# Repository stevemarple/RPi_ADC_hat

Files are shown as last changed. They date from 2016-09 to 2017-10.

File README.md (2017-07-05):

# Raspberry Pi ADC hat

A Raspberry Pi hat using the Microchip MCP3424 analogue to digital
converter. The hat also has connectors for I2C and 1-wire interfaces,
and two switched outputs, for instance to control fans, motors or
relays. A Honeywell HIH6130-021 or HIH6131-021 I2C temperature and
humidity sensor can also be fitted.

## Hardware features

### Analogue to digital converter

The MCP3424 is a 4 channel 18 bit differential input analogue to
digital converter. Sample rates are 3.75 SPS (samples per second) at
18 bit resolution, 15 SPS at 16 bit resolution, 60 SPS at 14 bit
resolution and 240 SPS at 12 bit resolution. When single-ended inputs
are used the resolution is reduced by 1 bit. A jumper block enables
the I2C address of the MCP3424 to be selected from eight possible
values. The ADC inputs are directly wired to a 9 pin D connector, 3
channels can be used for differential inputs, the fourth for
single-ended measurements only. Optional decoupling capacitors can be
added to all inputs; alternatively zero ohm resistors may be used to
convert the differential inputs to single-ended.

### I2C interface

The buffered I2C interface is made available via an RJ11 connector,
allowing additional MCP3424 devices or other I2C devices to be
connected, eg the AuroraWatchNet magnetometer sensor head
(https://github.com/stevemarple/AuroraWatchNet/tree/master/hardware/FLC100_shield/remote_v2). 

### 1-wire interface

A connector for a 1-wire interface is provided. The 3 pin Molex
connector also connects to the Raspberry Pi's 3.3V supply so that it
is not necessary to use parasitic power operation.

### Power supplies

All power is used is taken from the Raspberry Pi via the GPIO
header. The 1 wire interface, I2C buffer and HAT EEPROM are connected
to the Pi's 3.3V supply, all other power is derived from the 5V
supply. Changes in the CPU load on the Pi can result in small supply
voltage variations due to voltage sag from the Pi's power supply. When
sensors and the ADC are powered directly from the Pi's 5V supply this
can result in spurious measurements. To combat this effect a DC-DC
converter and linear regulator can be fitted to derive a stable
analogue voltage supply.

### Switched outputs

Two switched outputs are provided which can be connected to fans,
motors, relays etc. Flyback diodes can be fitted to allow safe switching
of inductive loads.

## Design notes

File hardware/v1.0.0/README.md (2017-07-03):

# Build instructions for v1.0.0

The PCB design offers a number of options for construction, not all
parts should fitted. Indeed, to do so could be harmful to the ADC
HAT and to the Raspberry Pi. Read and understand the build options first.

## Build options

### Linear voltage regulator

Decide upon the analogue supply voltage for your application. The
analogue voltage sets the operating voltage for MCP3424 ADC, and the
signal levels for the buffered section of the I2C bus. There are four
options:

1. For 3.3V operation fit a Microchip TC1262-33VDB. Do not fit the
DC-DC converter, instead fit the DC-DC converter link wire.
2. For a clean 5V analogue supply fit a Microchip MCP1790-5002E/DB
voltage regulator and a DC-DC converter.
3. To reuse the Raspberry Pi's 5V supply (not recommended) do not fit
a voltage regulator and do not fit the DC-DC converter. Fit the link
wires for both the DC-DC converter and the voltage regulator.
4. To delegate the analogue voltage supply generation to an external
board connected via the I2C interface connector X1 do not fit the
voltage regulator or the voltage regulator link wire. Whether the
DC-DC converter should also be fitted depends on the input voltage
required for the external regulator; it can be powered from either the
Pi's 5V supply or the DC-DC converter's output, selected by the
position of the jumper on JP1.

Under no circumstances should the linear regulator and its link wire
be fitted.

Fit JP1 only if option 4 is selected.

### DC-DC converter

The standard DC-DC converter is the  Traco TME0509S. Alternatives
include the Murata NME0509SC and the Recom Power RO-0509S. All
convert 5V DC to 9V DC. Provided the recommended voltage ratings for
the capacitors are followed it is also possible to use 5V to 12V DC-DC
converters.

The reference build is to include a DC-DC converter. If one is not
required then a link wire can be fitted in its place. Under no
circumstances should a DC-DC converter be fitted and its link wire.

It is also possible to use an external supply instead of the DC-DC
converter by fitting a Molex 22-23-2041 connector in its place.

If it is found that the load on the DC-DC converter is insufficient
for correct operation it is possible to fit an optional load resistor
(R3). Do not exceed power rating for the resistor; a 1210
surface-mount resistor can be fitted which is likely to have a higher
rating than the 1206 package.

### ADC

If the onboard ADC is not required (for instance, using external
devices connected to the I2C interface) then omit U4, U6, C6, C11, C12,
C13, C14, C15, C16, C17, X2 and JP2. The reference build is to fit U4,
C6, X2 and JP2.

Decoupling capacitors for the positive inputs of channels 1 (C11), 2
(C12), 3 (C13) and 4 (C14) can be fitted if required. The suggested
value is 100p but the correct value depends on application. Decoupling
capacitors for the negative differential inputs of channels 1 (C15), 2
(C16) and 3 (C17) can also be added. The correct value should probably
match the corresponding decoupling on the positive input but will vary
by application. In the case of single-ended inputs the negative
differential input can be grounded by fitting a zero ohm resistor
instead. Channel 4 is wired as single-ended input only.

### Analogue board temperature

If channel 4 of the onboard ADC is not used then the circuit board
temperature can be monitored by fitting an LM61BIM3 or LM61CIM3
temperature sensor to U6. Also fit C14 (100n).

### Digital humidity and temperature measurement

Relative humidity can be monitored by fitting a Honeywell HIH6130-021
or HIH6131-021 sensor to U3. (Do not confuse these versions with the
similarly-named SPI versions.) Also fit C8 and C9. The sensor also
provides a digital temperature output.

### HAT EEPROM

For compliance with the HAT specifications an EEPROM must be fitted
and programmed accordingly. The recommended part is ON Semiconductor
CAT24C32WI-GT3. Larger capacities, eg ON Semiconductor CAT24C64WI-GT3,
can be fitted instead. In addition to U7 also fit R7, R8, R9, C18 and
JP3. These parts can be omitted if desired but the board cannot be
called a HAT.

Software and instructions for programming the EEPROM can
be found in the Raspberry Pi hats repository, see 
https://github.com/raspberrypi/hats/tree/master/eepromutils.
Predefined device tree configuration files can be found in the
[firmware](../../firmware) directory.

### Switched outputs

Two independent switched 5V outputs can be included to control fans,
motors or relays. For the first switched output fit Q1, R10, R12 C19
and D1 and X4. For the second switched output fit Q2, R11, R13, C20,
D2 and X5. The flyback diodes are essential when inductive loads are
switched.

### External I2C interface

The buffered I2C interface can be made available to external devices
by fitting a 6P6C registered jack to X1. The external buffered side of
the I2C interface operates at the analogue supply voltage.

### 1 wire interface

If the 1 wire interface is desired fit R6 and Molex connector X3. The
interface operates at 3.3V and does not buffer the Raspberry Pi's GPIO
pins - use with caution! RJ11 connectors are frequently used for 1
wire interfaces, do not confuse the RJ11 connector used for the
external I2C interface with the 1 wire interface on the Molex
connector.

## Order of construction

The recommended general order of construction is to solder the top
side components first. Begin with the finest pitch and lowest height
components. Integrated circuits (U3, U4, and U5) should be soldered
first, then the surface mount resistors and capacitors. Then solder
the voltage regulator (U1) and FETs (Q1, Q2). If any components are to
be soldered to the underside turn over and solder those. Then add the
DC-DC converter (U2), the jumper blocks and then the
connectors. Remember that the 40 pin connector is fitted to the
underside (solder from top-side). If any link wires are to be
installed add them last, they provide the ability to test parts of the
circuit separately.

## Bill of materials (BOM)

BOMs for several different build configurations, including the
reference design, can be found in the
[bill_of_materials](bill_of_materials) directory.

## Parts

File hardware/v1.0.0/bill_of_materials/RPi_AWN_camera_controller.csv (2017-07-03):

Part | Value | Device | Package | Description | MF | MPN | OC_FARNELL | OC_NEWARK | OC_CPC
C1 | 4u7 | C-EU1206-HAND | 1206-HAND | Ceramic capacitor | Multicomp | MC1206B475K250CT | 2320886
C2 | 100n | C-EU1206-HAND | 1206-HAND
C3 | 4u7 | CAP_POL1210-HAND | CPOL-1210-HAND | Tantalum capacitor 35V | AVX | TAJB475K035RNJ | 197592
C4 | 100n | C-EU1206-HAND | 1206-HAND
C5 | 4u7 | CAP_POL1210-HAND | CPOL-1210-HAND | Tantalum capacitor 35V | AVX | TAJB475K035RNJ | 197592
C6 | 100n | C-EU1206-HAND | 1206-HAND
C7 | 100n | C-EU1206-HAND | 1206-HAND
C8 | 220n
C9 | 100n | C-EU1206-HAND | 1206-HAND
C10 | 100n | C-EU1206-HAND | 1206-HAND
C11 | 100n | C-EU1206-HAND | 1206-HAND
C12 | 100n | C-EU1206-HAND | 1206-HAND
C13 | 100n | C-EU1206-HAND | 1206-HAND
C14 | 100n | C-EU1206-HAND | 1206-HAND
C15 | 0R resistor | C-EU1206-HAND | 1206-HAND
C16 | 0R resistor | C-EU1206-HAND | 1206-HAND
C17 | 0R resistor | C-EU1206-HAND | 1206-HAND
C18 | 100n | C-EU1206-HAND | 1206-HAND
D1 | BAS21 | SOT23-3-HAND
D2 | BAS21 | SOT23-3-HAND
JP2 | I2C ADDRESS | PINHD-2X3 | 2X03 | PIN HEADER
JP3 | PROG | JUMPER-2PTH | 1X02 | Jumper
L1 | 15u | INDUCTOR1210-HAND | 1210-HAND | Inductor | TDK | NLCV32T-150K-EF | 2429397
Q1 | FDT439N | SOT223-HAND
Q2 | FDT439N | SOT223-HAND
R3 | 1k | RESISTOR1206-HAND | 1206-HAND |  | Vishay | CRCW12061K00FKEA | 1469965
R4 | 4k7 | RESISTOR1206-HAND | 1206-HAND
R5 | 4k7 | RESISTOR1206-HAND | 1206-HAND
R7 | 1k | RESISTOR1206-HAND | 1206-HAND |  | Vishay | CRCW12061K00FKEA | 1469965
R8 | 3k9 | RESISTOR1206-HAND | 1206-HAND |  | Welwyn | WCR1206-3K9FI | 1100206
R9 | 3k9 | RESISTOR1206-HAND | 1206-HAND |  | Welwyn | WCR1206-3K9FI | 1100206
R10 | 560R | RESISTOR1206-HAND | 1206-HAND
R11 | 560R | RESISTOR1206-HAND | 1206-HAND
R12 | 1M | RESISTOR1206-HAND | 1206-HAND
R13 | 1M | RESISTOR1206-HAND | 1206-HAND
U1 | TC1262-33VDB | MCP1790-5002E/DB | SOT223-HAND |  |  |  | 1852183
U3 | HIH6130-021-001 | SO08 | SO08 | I2C humidity sensor | Honeywell | HIH6130-021-001 | 1961727 |  | SN36728
U4 | MCP3424 | MCP3424-E/SLSO14 | SO14 | Analog-to-Digital Converter | Microchip | MCP3424-E/SL | 1630424
U5 | PCA9517A | PCA9517ASOIC |  |  | NXP | PCA9517AD,112 | 2400580
U6 | LM61 | SOT23-3-HAND
U7 | C24C64 | EEPROM-C24CXXSOIC8 | SO08 |  | ON Semiconductor | CAT24C64WI-GT3 | 2463718
X2 | ADC |  |  | DSUB 9PIN Vertical | AMP – TE | 3-1634222-2 | 5082055 |  | CN15094
X4 | AUX1 | 22-23-2021
X5 | AUX2 | 22-23-2021

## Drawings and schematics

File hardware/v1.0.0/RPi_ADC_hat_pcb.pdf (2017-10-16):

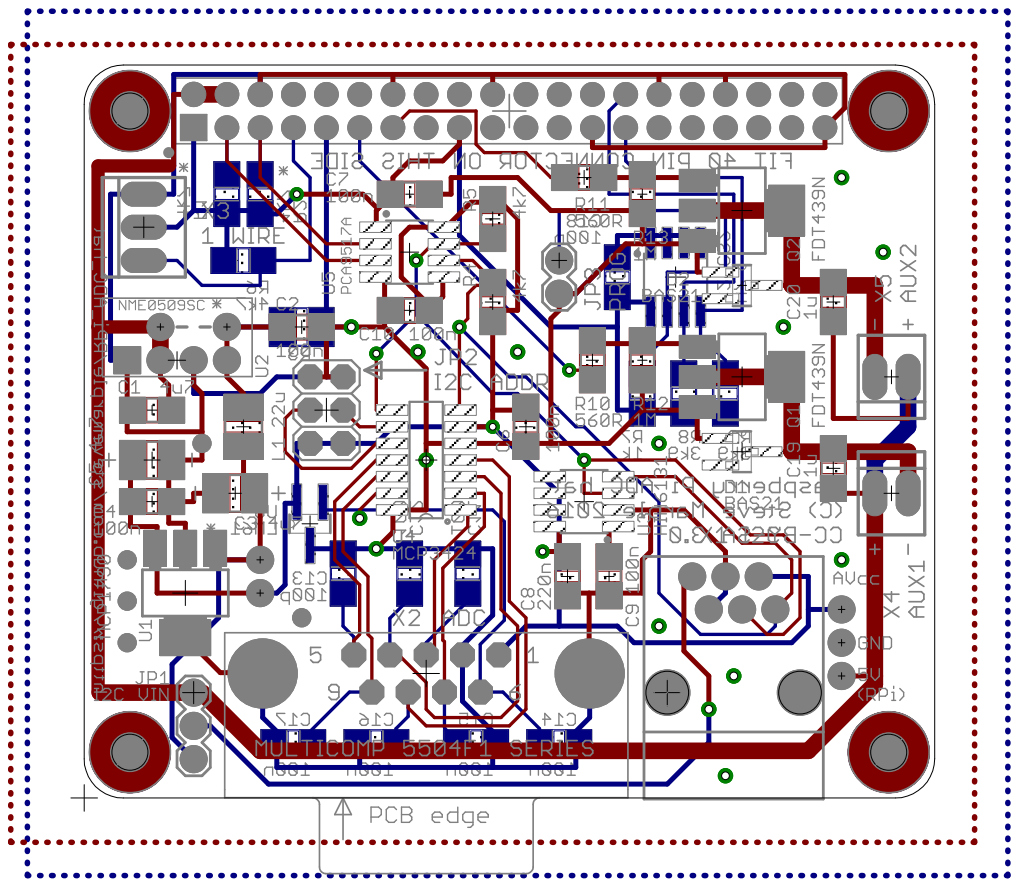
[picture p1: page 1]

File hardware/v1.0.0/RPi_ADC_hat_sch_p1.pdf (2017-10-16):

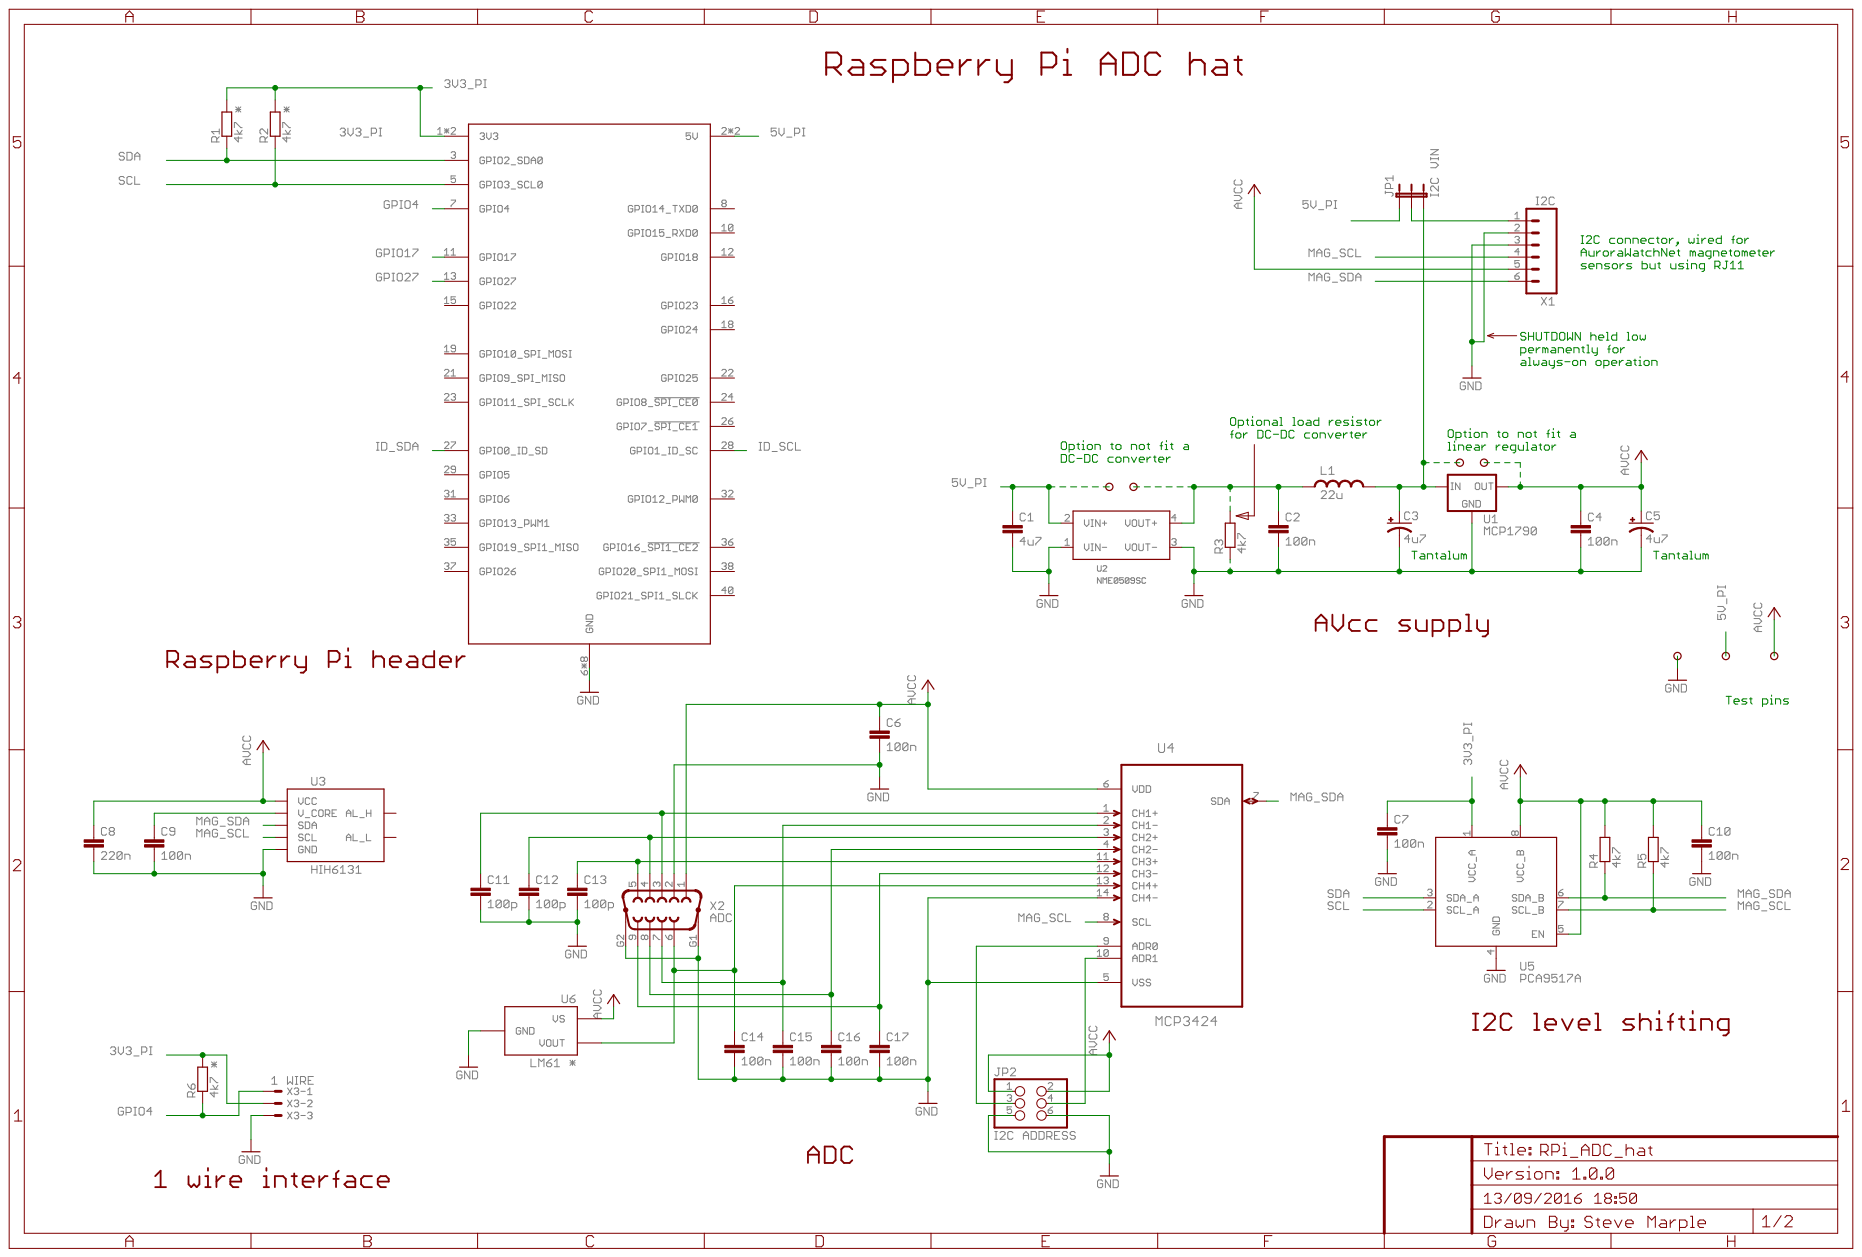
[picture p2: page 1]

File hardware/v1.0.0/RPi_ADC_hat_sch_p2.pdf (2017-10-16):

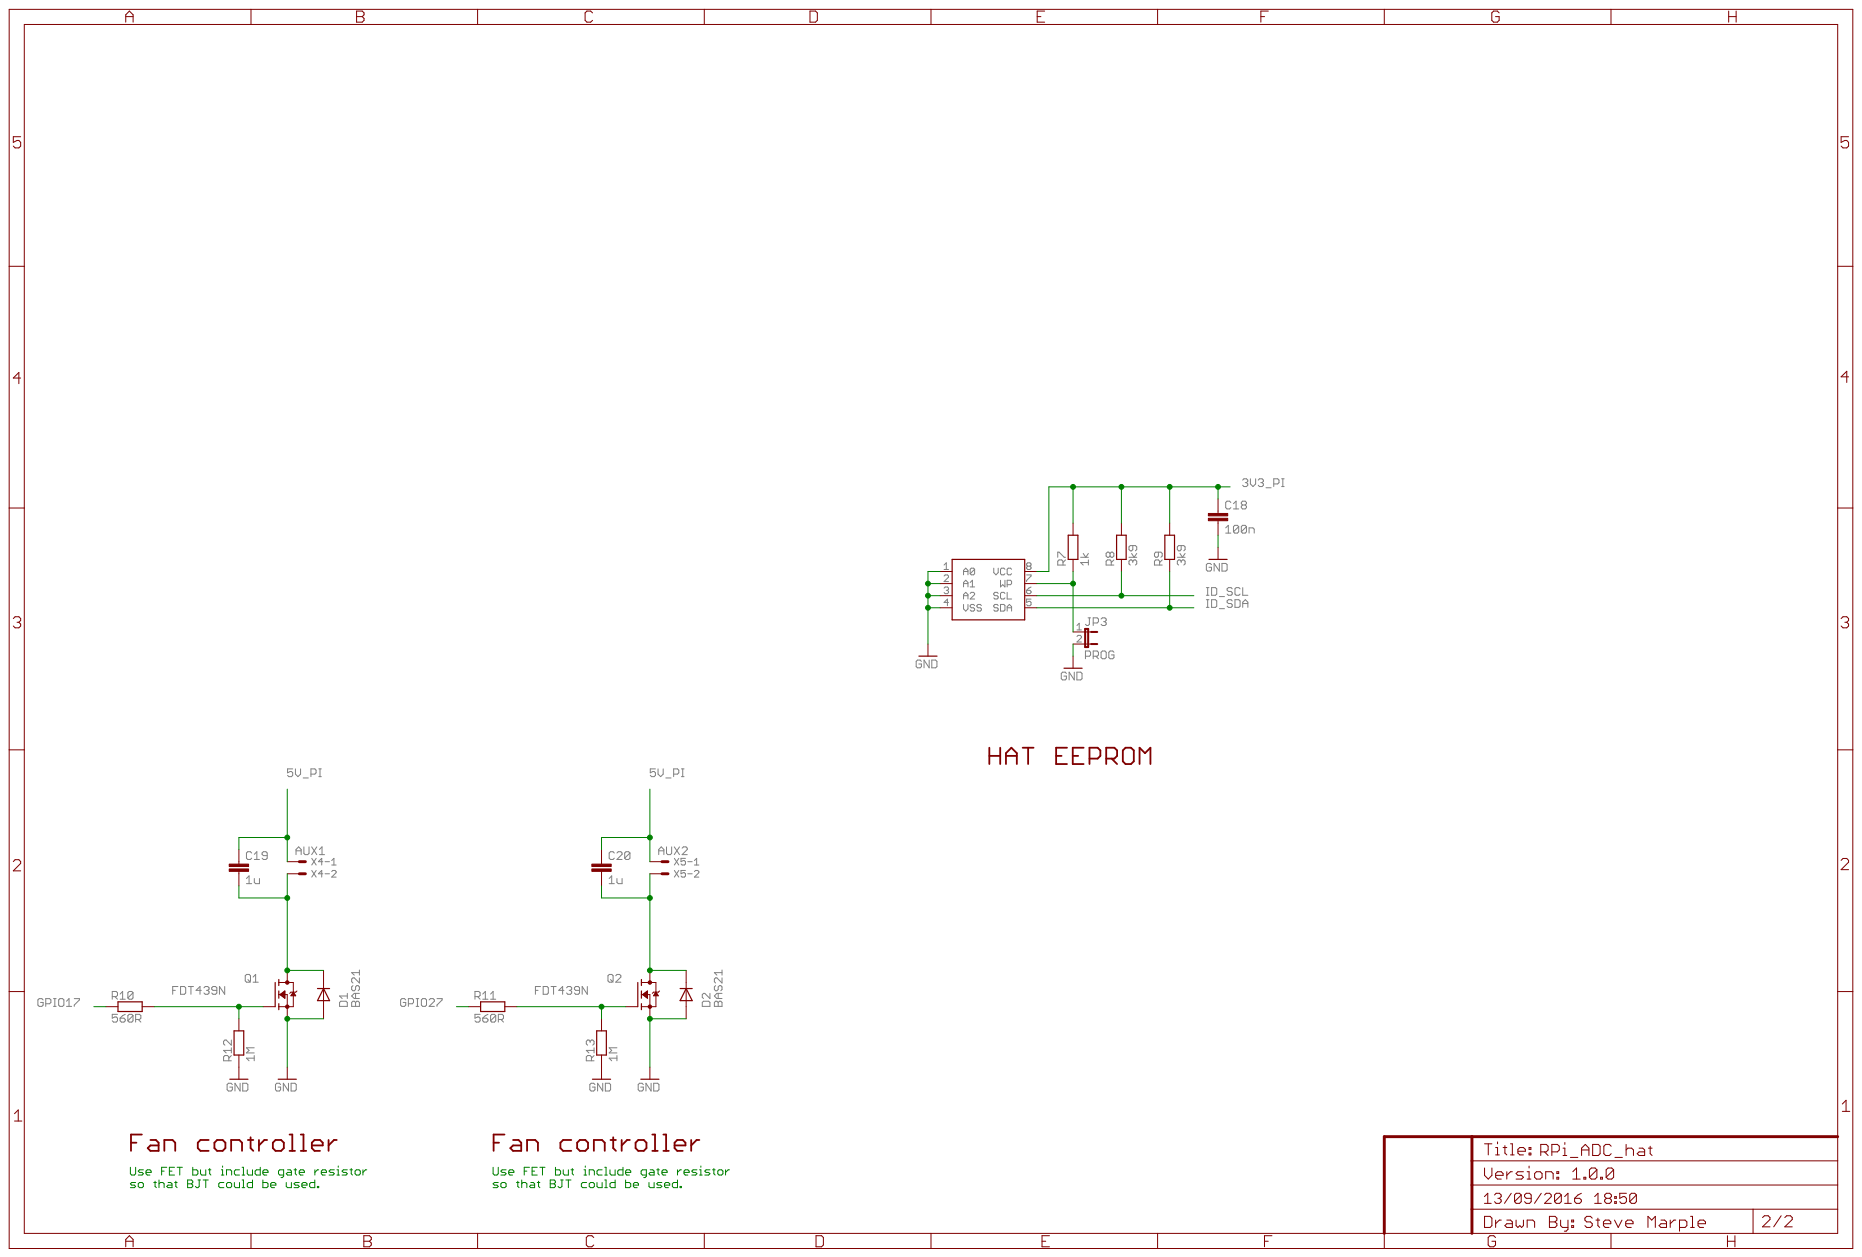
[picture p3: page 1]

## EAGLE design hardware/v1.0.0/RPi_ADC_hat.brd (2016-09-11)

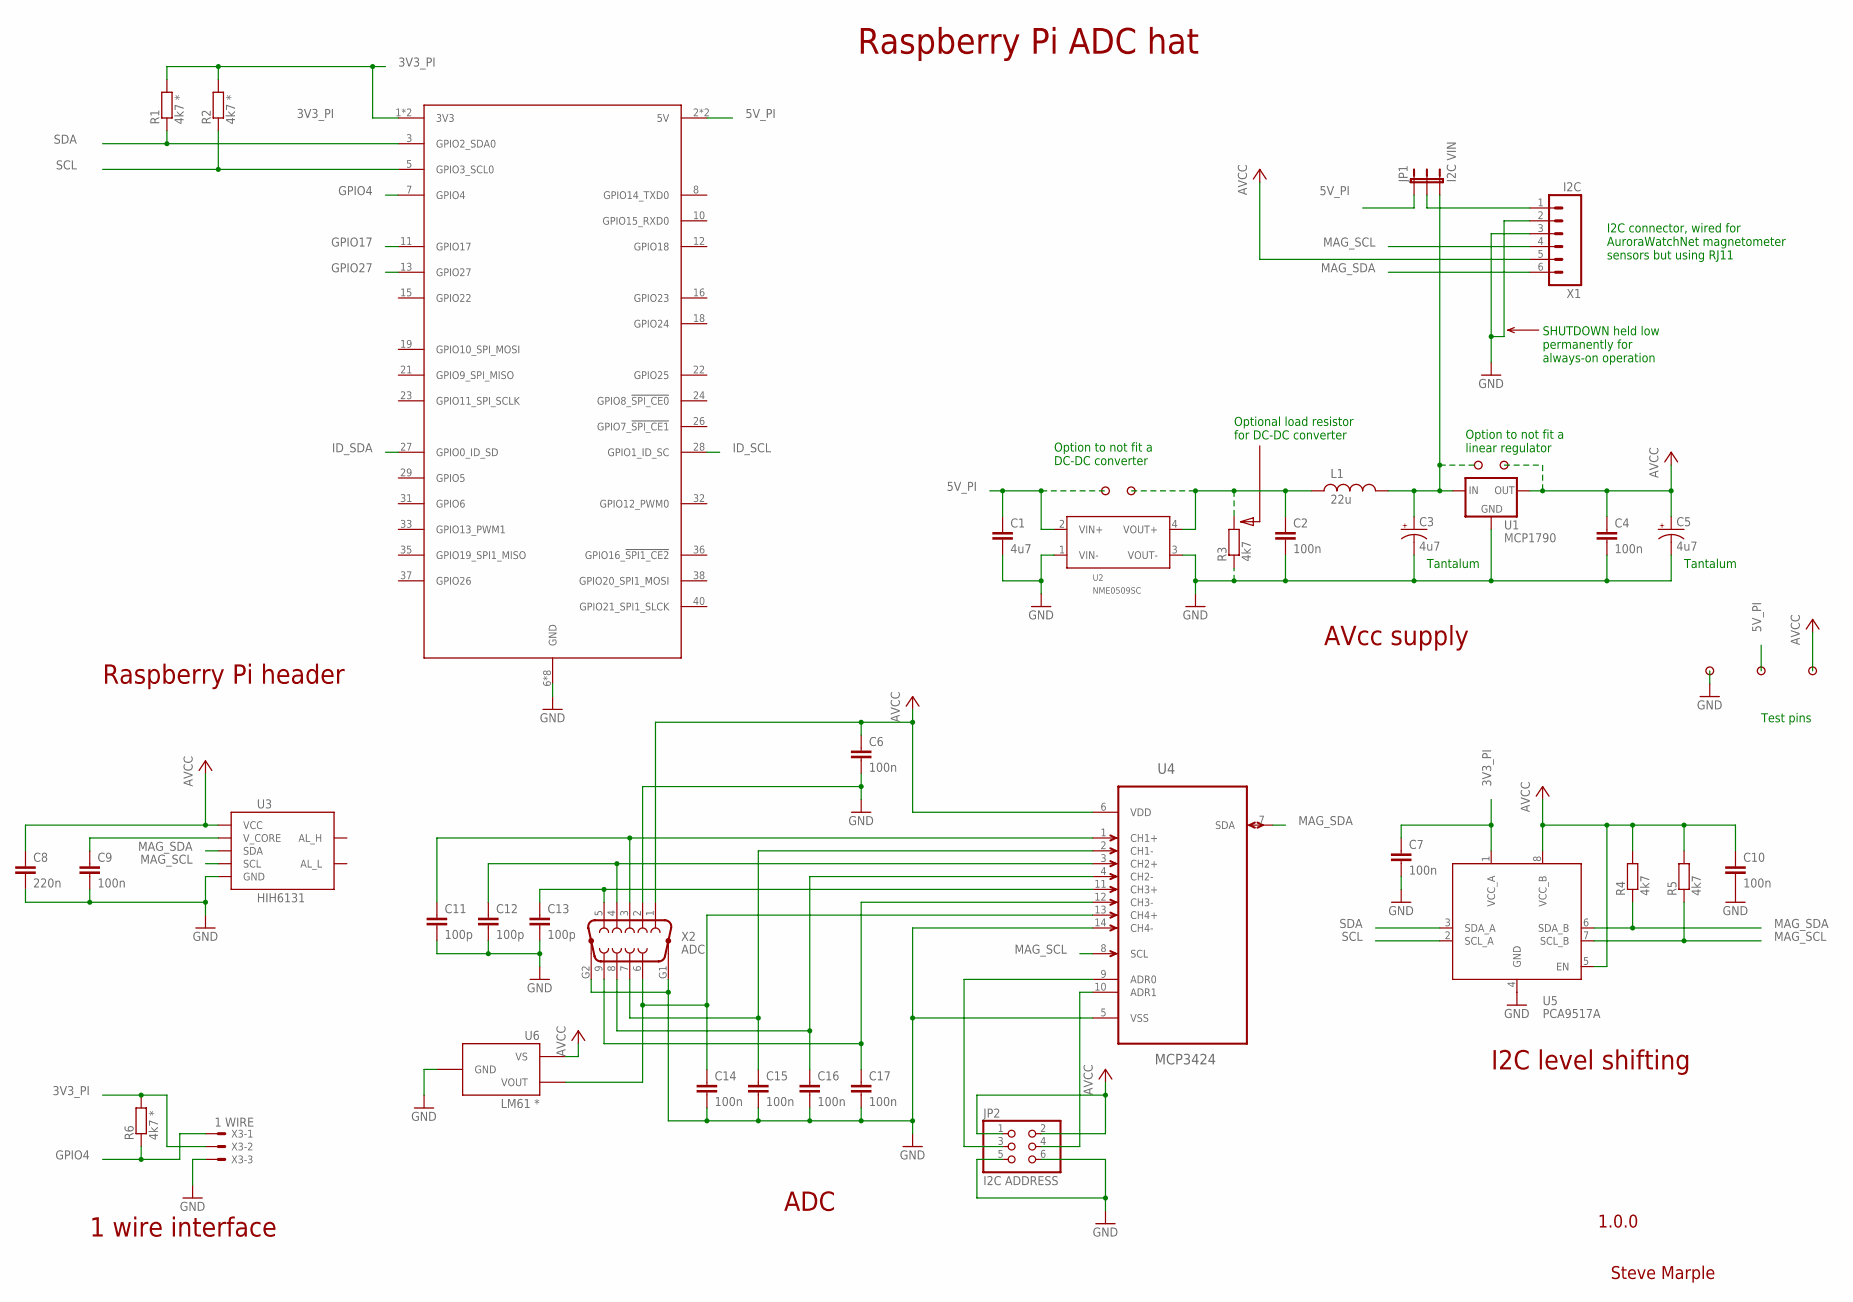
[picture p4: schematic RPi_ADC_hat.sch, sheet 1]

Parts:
C1: 4u7; 1206-HAND
C2, C4, C6, C7, C9, C10, C14, C15, C16, C17: 100n; 1206-HAND
C3, C5: 4u7; CPOL-1210-HAND
C8: 220n; 1206-HAND
C11, C12, C13: 100p; 1206-HAND
JP1: I2C VIN; 1X03
JP2: I2C ADDRESS; 2X03
L1: 22u; 1210-HAND
R1, R2, R6: 4k7 *; 1206-HAND
R3: 4k7; 1210-HAND
R4, R5: 4k7; 1206-HAND
U1: MCP1790; SOT223-HAND
U2: NME0509SC; DC-DC-MURATA-NME-05-12-SERIES
U3: HIH6131; SO08
U4: MCP3424; SO14
U5: PCA9517A; SO08
U6: LM61 *; SOT23-3-HAND
U$1: PCB; RASPBERRY-PI-3
U$2, U$3, U$4, U$5, U$6, U$7, U$8: PAD
X1: I2C; RJ11-6
X2: ADC; DSUB-5504F1-02-9PIN
X3: 1 WIRE; 22-23-2031

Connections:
3V3_PI: C7.1, R1.2, R2.2, R6.2, U5.1 (VCC_A), U$1.1 (3V3), U$1.17 (3V3), X3.2; also elsewhere on the board
5V_PI: C1.1, JP1.1, U2.2 (VIN+), U$1.2 (5V), U$1.4 (5V), U$4.1, U$7.1; also elsewhere on the board
AVCC: C4.1, C5.+, C6.1, C8.1, C10.1, JP2.1, JP2.2, R4.2, R5.2, U1.3 (OUT), U3.8 (VCC), U4.6 (VDD), U5.5 (EN), U5.8 (VCC_B), U6.1 (VS), U$3.1, U$8.1, X1.5, X2.1
CH1+: C11.1, U4.1 (CH1+), X2.3
CH1-: C15.1, U4.2 (CH1-), X2.7
CH2+: C12.1, U4.3 (CH2+), X2.4
CH2-: C16.1, U4.4 (CH2-), X2.8
CH3+: C13.1, U4.11 (CH3+), X2.5
CH3-: C17.1, U4.12 (CH3-), X2.9
CH4+: C14.1, U4.13 (CH4+), U6.2 (VOUT), X2.6
DC-DC_OUT: C3.+, JP1.3, L1.2, U1.1 (IN), U$2.1
DC-DC_UNFILTERED: C2.1, L1.1, R3.2, U2.4 (VOUT+), U$5.1
GND: C1.2, C2.2, C3.-, C4.2, C5.-, C6.2, C7.2, C8.2, C9.2, C10.2, C11.2, C12.2, C13.2, C14.2, C15.2, C16.2, C17.2, JP2.5, JP2.6, R3.1, U1.2 (GND), U1.4 (GND), U2.1 (VIN-), U2.3 (VOUT-), U3.2 (GND), U4.5 (VSS), U4.14 (CH4-), U5.4 (GND), U6.3 (GND), U$1.6 (GND), U$1.9 (GND), U$1.14 (GND), U$1.20 (GND), U$1.25 (GND), U$1.30 (GND), U$1.34 (GND), U$1.39 (GND), U$6.1, X1.2, X1.3, X2.2, X2.G1, X2.G2, X3.3; also elsewhere on the board
GPIO4: R6.1, U$1.7 (GPIO4), X3.1
GPIO17: U$1.11 (GPIO17); also elsewhere on the board
GPIO27: U$1.13 (GPIO27); also elsewhere on the board
HIH_VCORE: C9.1, U3.1 (V_CORE)
I2C_VIN: JP1.2, X1.1
ID_SCL: U$1.28 (GPIO1_ID_SC); also elsewhere on the board
ID_SDA: U$1.27 (GPIO0_ID_SD); also elsewhere on the board
MAG_SCL: R5.1, U3.3 (SCL), U4.8 (SCL), U5.7 (SCL_B), X1.4
MAG_SDA: R4.1, U3.4 (SDA), U4.7 (SDA), U5.6 (SDA_B), X1.6
unnamed: JP2.3, U4.9 (ADR0)
unnamed: JP2.4, U4.10 (ADR1)
SCL: R2.1, U5.2 (SCL_A), U$1.5 (GPIO3_SCL0)
SDA: R1.1, U5.3 (SDA_A), U$1.3 (GPIO2_SDA0)

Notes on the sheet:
Steve Marple
1.0.0
SHUTDOWN held low permanently for always-on operation
Raspberry Pi ADC hat
AVcc supply
Option to not fit a DC-DC converter
Tantalum
Optional load resistor for DC-DC converter
1 wire interface
I2C level shifting
ADC
Raspberry Pi header
Test pins
Option to not fit a linear regulator
I2C connector, wired for AuroraWatchNet magnetometer sensors but using RJ11

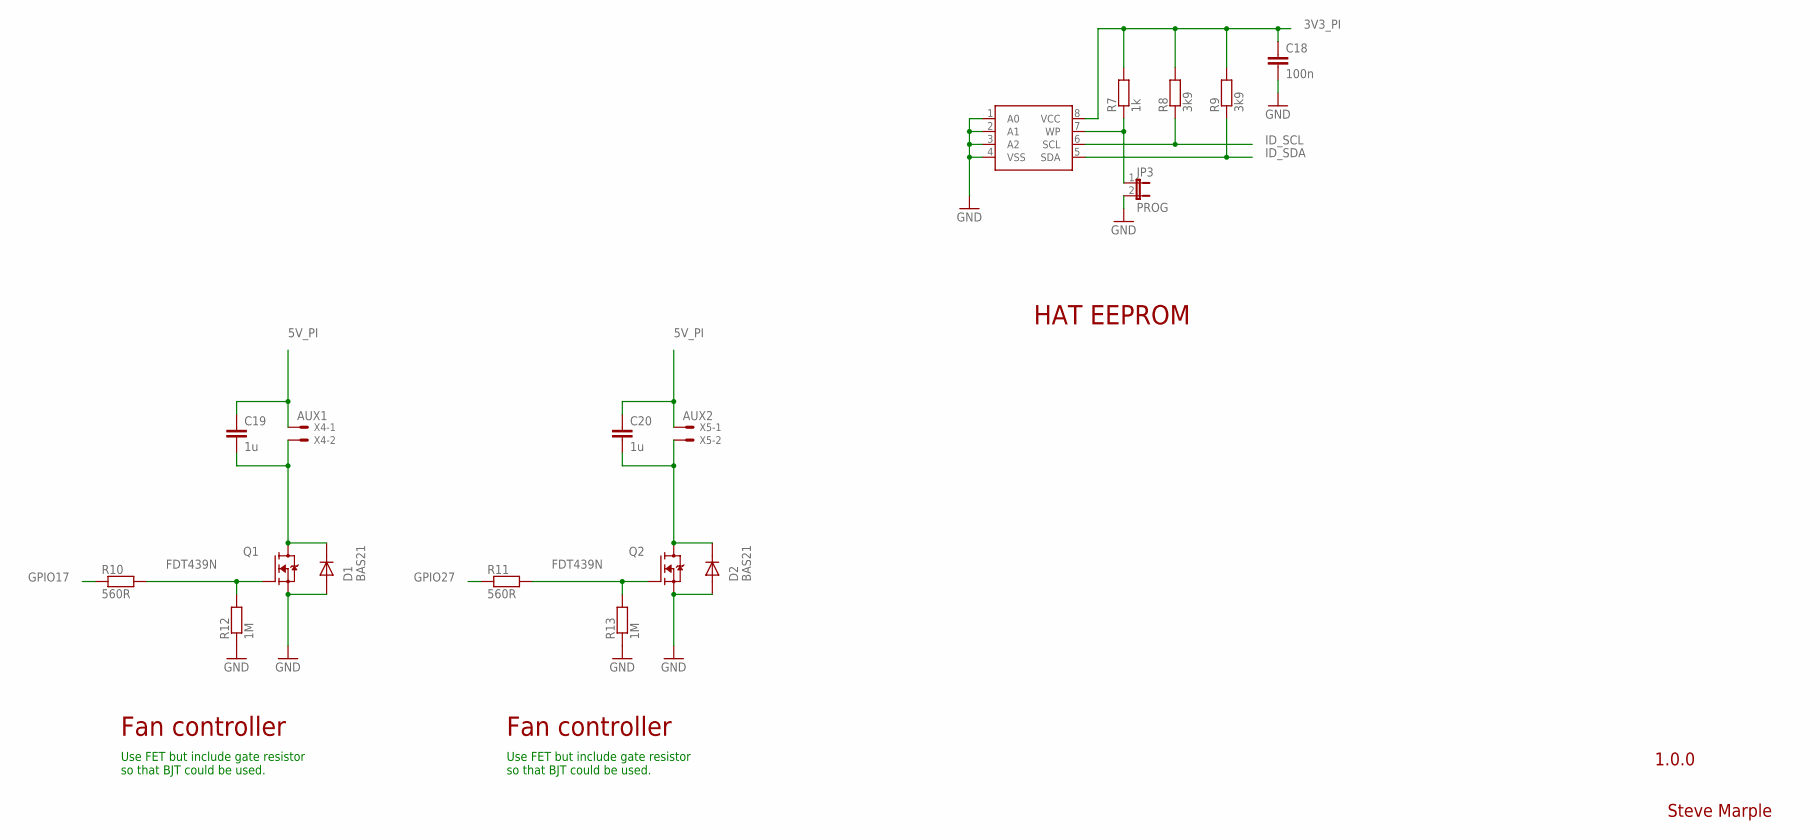
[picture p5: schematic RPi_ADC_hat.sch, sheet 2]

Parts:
C18: 100n; 1206-HAND
C19, C20: 1u; 1206-HAND
D1, D2: BAS21; SOT23-3-HAND
JP3: PROG; 1X02
Q1, Q2: FDT439N; SOT223-HAND
R7: 1k; 1206-HAND
R8, R9: 3k9; 1206-HAND
R10, R11: 560R; 1206-HAND
R12, R13: 1M; 1206-HAND
U7: C24C32; SO08
X4: AUX1; 22-23-2021
X5: AUX2; 22-23-2021

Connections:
3V3_PI: C18.1, R7.2, R8.2, R9.2, U7.8 (VCC); also elsewhere on the board
5V_PI: C19.1, C20.1, X4.1, X5.1; also elsewhere on the board
EEPROM_WP: JP3.1, R7.1, U7.7 (WP)
FAN1_CTRL: C19.2, D1.3 (C), Q1.2 (D), Q1.4 (D), X4.2
FAN2_CTRL: C20.2, D2.3 (C), Q2.2 (D), Q2.4 (D), X5.2
GND: C18.2, D1.1 (A), D2.1 (A), JP3.2, Q1.3 (S), Q2.3 (S), R12.1, R13.1, U7.1 (A0), U7.2 (A1), U7.3 (A2), U7.4 (VSS); also elsewhere on the board
GPIO17: R10.1; also elsewhere on the board
GPIO27: R11.1; also elsewhere on the board
ID_SCL: R8.1, U7.6 (SCL); also elsewhere on the board
ID_SDA: R9.1, U7.5 (SDA); also elsewhere on the board
unnamed: Q2.1 (G), R11.2, R13.2
unnamed: Q1.1 (G), R10.2, R12.2

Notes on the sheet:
Fan controller
Use FET but include gate resistor so that BJT could be used.
Steve Marple
1.0.0
HAT EEPROM

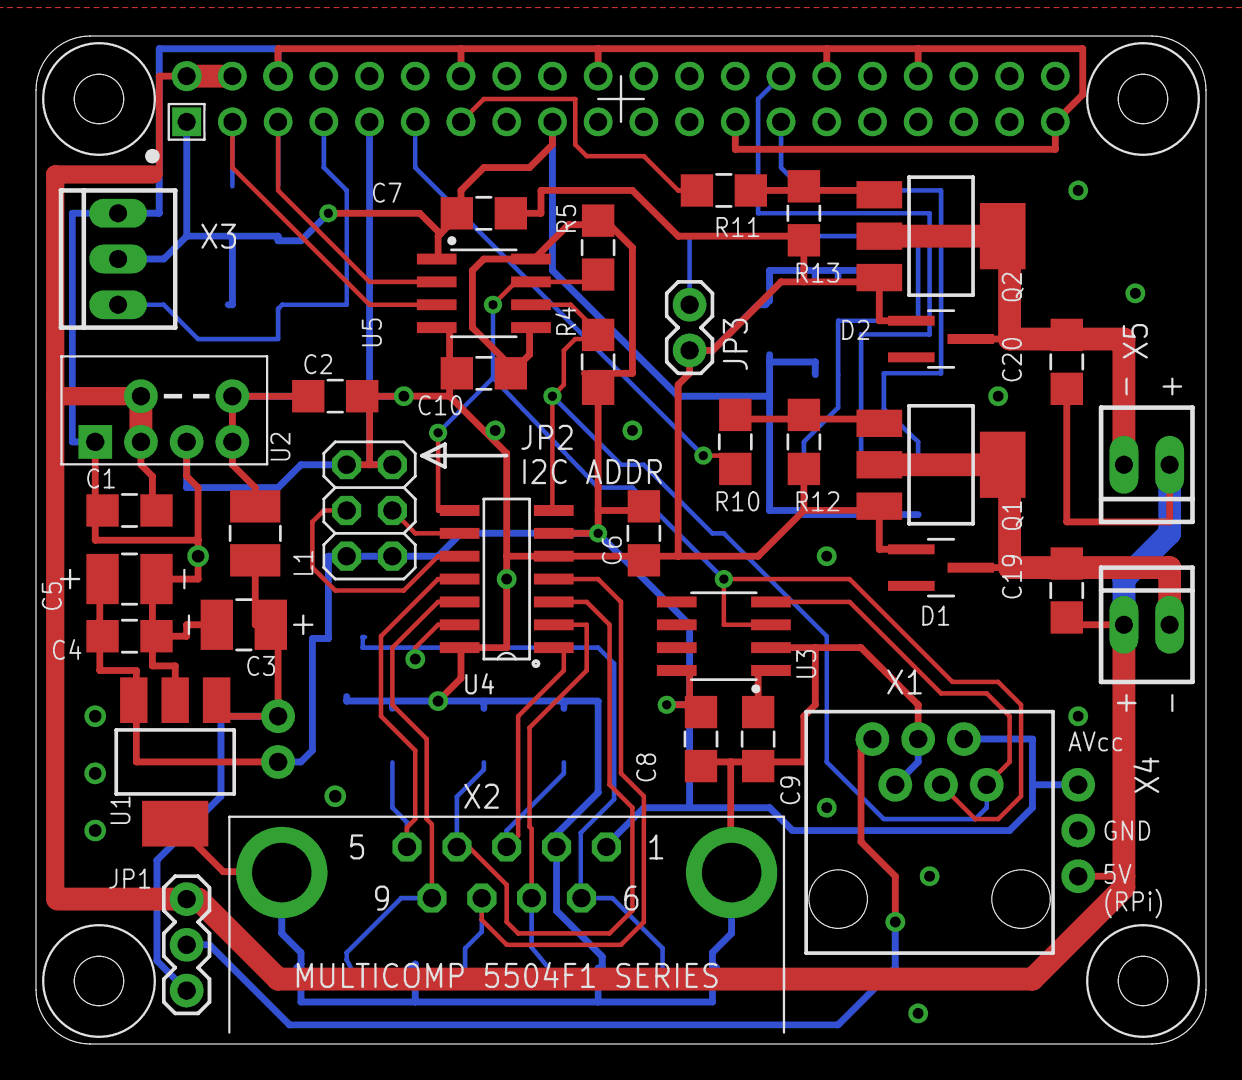
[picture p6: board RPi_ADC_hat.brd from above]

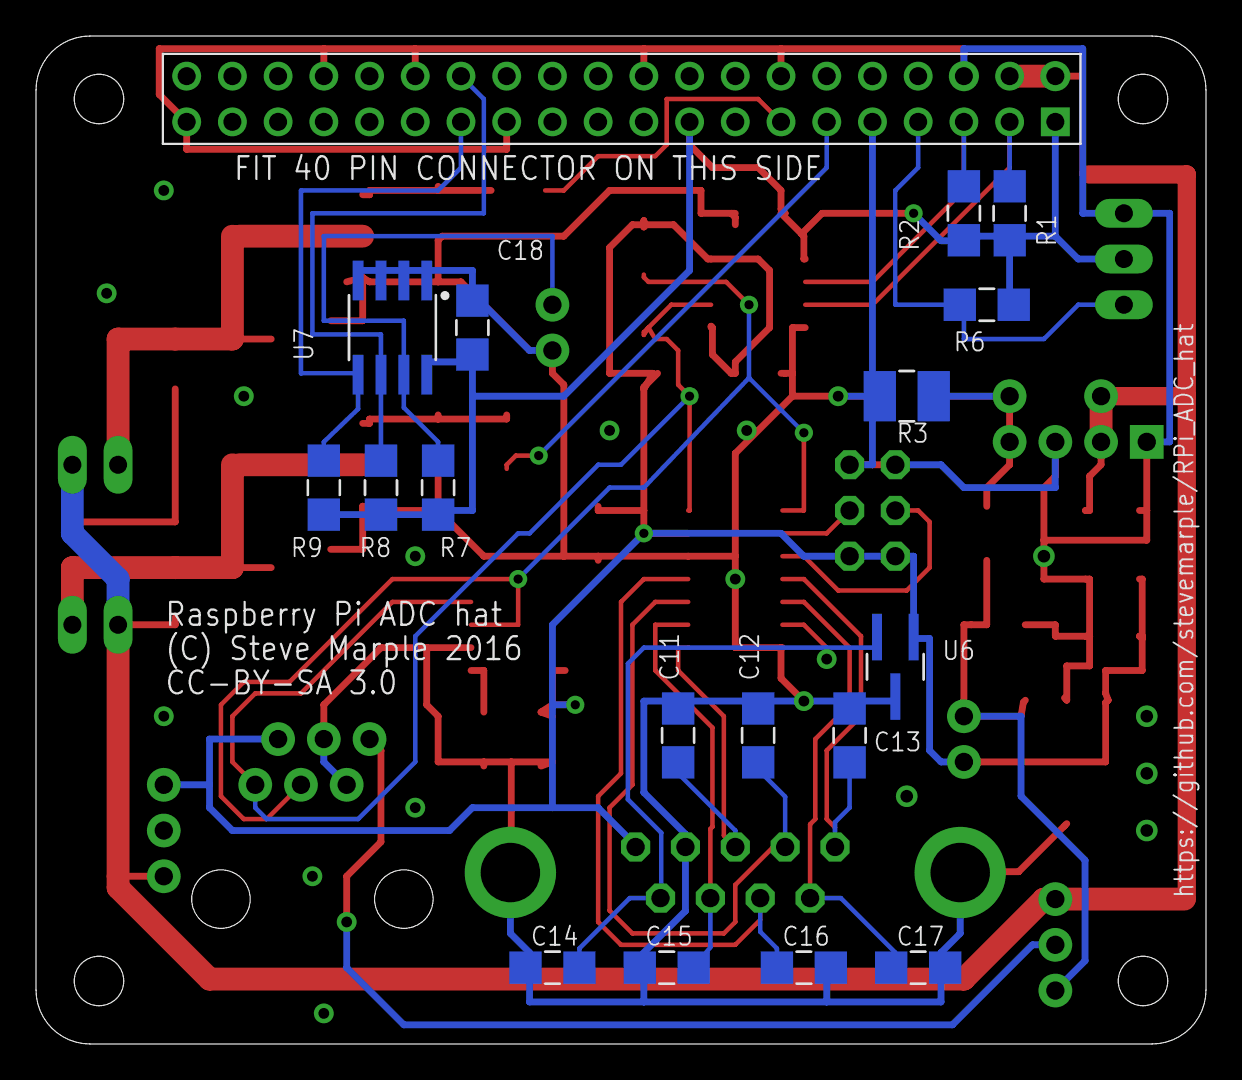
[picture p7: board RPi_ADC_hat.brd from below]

Board: 2 copper layers, 65.0 x 56.0 mm, 61 parts (17 on the bottom side), 31 nets.

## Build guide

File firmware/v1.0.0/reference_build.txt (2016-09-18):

########################################################################
# EEPROM settings text file
#
# Edit this file for your particular board and run through eepmake tool,
# then use eepflash tool to write to attached HAT ID EEPROM 
#
# Tools available:
#  eepmake   Parses EEPROM text file and creates binary .eep file
#  eepdump   Dumps a binary .eep file as human readable text (for debug)
#  eepflash  Write or read .eep binary image to/from HAT EEPROM
#
########################################################################

########################################################################
# Vendor info

# 128 bit UUID. If left at zero eepmake tool will auto-generate
# RFC 4122 compliant UUID
product_uuid 00000000-0000-0000-0000-000000000000

# 16 bit product id
product_id 0x0001

# 16 bit product version
product_ver 0x0001

# ASCII vendor string  (max 255 characters)
vendor "Steve Marple"

# ASCII product string (max 255 characters)
product "Raspberry Pi ADC hat"

########################################################################
# GPIO bank settings, set to nonzero to change from the default.
# NOTE these setting can only be set per BANK, uncommenting any of
# these will force the bank to use the custom setting.

# drive strength, 0=default, 1-8=2,4,6,8,10,12,14,16mA, 9-15=reserved
gpio_drive 0

# 0=default, 1=slew rate limiting, 2=no slew limiting, 3=reserved
gpio_slew 0

# 0=default, 1=hysteresis disabled, 2=hysteresis enabled, 3=reserved
gpio_hysteresis 0

# If board back-powers Pi via 5V GPIO header pins:
# 0 = board does not back-power
# 1 = board back-powers and can supply the Pi with a minimum of 1.3A
# 2 = board back-powers and can supply the Pi with a minimum of 2A
# 3 = reserved
# If back_power=2 then USB high current mode will be automatically 
# enabled on the Pi
back_power 0

########################################################################
# GPIO pins, uncomment for GPIOs used on board
# Options for FUNCTION: INPUT, OUTPUT, ALT0-ALT5
# Options for PULL: DEFAULT, UP, DOWN, NONE
# NB GPIO0 and GPIO1 are reserved for ID EEPROM so cannot be set

#         GPIO  FUNCTION  PULL
#         ----  --------  ----
setgpio  2     ALT0     DEFAULT
setgpio  3     ALT0     DEFAULT
setgpio  4     INPUT     NONE
#setgpio  5     INPUT     DEFAULT
#setgpio  6     INPUT     DEFAULT
#setgpio  7     INPUT     DEFAULT
#setgpio  8     INPUT     DEFAULT
#setgpio  9     INPUT     DEFAULT
#setgpio  10    INPUT     DEFAULT
#setgpio  11    INPUT     DEFAULT
#setgpio  12    INPUT     DEFAULT
#setgpio  13    INPUT     DEFAULT
#setgpio  14    INPUT     DEFAULT
#setgpio  15    INPUT     DEFAULT
#setgpio  16    INPUT     DEFAULT
setgpio  17    OUTPUT     DOWN
#setgpio  18    INPUT     DEFAULT
#setgpio  19    INPUT     DEFAULT
#setgpio  20    INPUT     DEFAULT
#setgpio  21    INPUT     DEFAULT
#setgpio  22    INPUT     DEFAULT
#setgpio  23    INPUT     DEFAULT
#setgpio  24    INPUT     DEFAULT
#setgpio  25    INPUT     DEFAULT
#setgpio  26    INPUT     DEFAULT
setgpio  27    OUTPUT     DOWN

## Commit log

2016-09-11 Increase gate resistors, renumber parts
    Resistors on FET gate increased to more closely match the value
    that would be needed if the FET is replaced by a BJT.
    [RPi_ADC_hat.brd, RPi_ADC_hat.sch]
2016-09-11 Minor fixes to silkscreen
    [RPi_ADC_hat.brd, RPi_ADC_hat.sch]
2016-09-11 Add Gerber files
    [RPi_ADC_hat.GBL, RPi_ADC_hat.GBO, RPi_ADC_hat.GBP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]
2016-09-11 Minor fix to text width
    Widtch of "LM61" increased from 8% to 10%.
    [RPi_ADC_hat.brd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]
2016-09-13 Add information about optional load resistor for DC-DC converter
2016-09-13 Add (partial) BOM for the reference design
    [reference_design.csv]
2016-09-18 Inital EEPROM settings for reference build
    I2C, 1-wire interfaces and both auxiliary switches included.
2016-09-24 Add column indicating which parts to be fitted
    Also add more manufacturer part numbers and order codes.
    [reference_design.csv]
2016-09-24 Add manufacturer part number and order code for R7
    [reference_design.csv]
2016-09-24 Add BOM for AuroraWatchNet Raspberry Pi magnetometer
    [RPI_AWN_magnetometer.csv]
2016-09-25 Fix build instructions
    [RPI_AWN_magnetometer.csv]
2016-09-29 Fix name
    [RPi_AWN_magnetometer.csv]
2016-09-29 Add firmware for AWN Raspberry Pi magnetometer build
2016-09-30 Remove parts from BOM which are not fitted
    [RPi_AWN_magnetometer.csv, reference_design.csv]
2016-11-09 Add device tree config for AuroraWatch UK camera controller
2017-06-27 Add BOM for camera controller
    [RPi_AWN_camera_controller.csv]
2017-06-27 Add humidity sensor part number and order codes
    [RPi_AWN_camera_controller.csv]
2017-06-28 Add inductor
    [RPi_AWN_camera_controller.csv]
2017-07-03 Add extra components
    C11, C12, C13: decoupling capacitors.
    C15, C16, C17: 0 ohm resistors to convert double-ended input to single-
    ended input by grounding -ve input.
    [RPi_AWN_camera_controller.csv]
2017-07-03 Link to predefined device tree config files
2017-07-05 Update information about flyback diodes
2017-10-16 Add schematic and PCB layout as PDFs

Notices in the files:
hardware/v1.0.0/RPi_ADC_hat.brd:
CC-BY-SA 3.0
